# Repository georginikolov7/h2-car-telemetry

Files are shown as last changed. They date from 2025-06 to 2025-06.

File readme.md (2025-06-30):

# 🏎️ Hydrogen Racing Car Telemetry – Battery Monitoring

This project enables **real-time battery telemetry** for a **hydrogen-powered racing car**, built for high school competitions. It reads battery capacity using a Seeed XIAO nRF52 BLE board and transmits it via **Bluetooth Low Energy (BLE)** to a **.NET MAUI mobile app**.

> Please read this document carefully to understand the setup, components, and how to continue development.

---

## 📦 Contents

- 📁 `xiaoble-source/` – Firmware code for the Seeed XIAO board (C++ with PlatformIO)
- 📁 `pcb/` – KiCad files for the electrical design
- 📁 `maui-source/` – code for the mobile app (C# MAUI framework)
- 📄 `README.md` – Project documentation (you are here)

---

## ⚙️ System Overview

- **Board**: Seeed XIAO nRF52 BLE
- **Function**: Reads battery voltage/capacity and transmits data via BLE
- **Receiver**: Mobile app built with .NET MAUI
- **Firmware**: C++ using PlatformIO + Bluefruit library

---

## 🧰 Tools & Dependencies

### Hardware

- Seeed XIAO nRF52 BLE board
- Battery and voltage measuring circuit (see `pcb/`)
- Bluetooth-capable mobile device (Android)

### Parameters to keep in mind
Battery:
- Minimal voltage before cut-off - 6.4V
- Maximal charge voltage - 8.6V
---
!!! Since battery voltage range IS OUTSIDE working range of the seeed XIAO board, a voltage divider circuit is used to reduce the supplied voltage before passing it to analog input on the board !!!
---
### Software

- [PlatformIO](https://platformio.org/) (for microcontroller firmware)
- [KiCad](https://kicad.org/) (for circuit schematics)
- [.NET MAUI](https://learn.microsoft.com/en-us/dotnet/maui/) (for the mobile app)

---

## 📚 Used Libraries

### 🧠 Microcontroller (Seeed XIAO nRF52 BLE)

- **[Adafruit Bluefruit nRF52 Library](https://github.com/adafruit/Adafruit_nRF52_Arduino)**  
  Provides BLE support for nRF52 chips. Used to advertise services, send battery data, and manage BLE characteristics.

> No additional installation required

### 📱 Mobile App (MAUI)

- [Plugin.BLE](https://github.com/xabre/xamarin-bluetooth-le) by xabre  
  Cross-platform BLE plugin for Xamarin/.NET MAUI. Used to scan, connect, and read BLE data from the XIAO board.

Add via NuGet:

```bash
dotnet add package Plugin.BLE
```
---
## 🛠️ Getting Started

### Hardware 
- Please familiarize yourselves with the schematic design and used components (the power )

### 🚀 Firmware Setup (Microcontroller)

1. Install [Visual Studio Code](https://code.visualstudio.com/) with the [PlatformIO extension](https://platformio.org/install).
2. Open the project folder in VSCode.
3. Connect the Seeed XIAO nRF52 BLE board via USB.
4. Upload the firmware:

```bash
pio run --target upload
```
## 💡 Future Improvement Ideas

### 🧪 Add sensors for:

- Measure consumed current(use a ready-made board with low quiescent current. Ideally it should not rely on shunt resistors as such ones consume more power)  

- Hydrogen flow measurement

- Motor/controller temperature

- Wheel speed or RPM

### 📱 Improve the mobile app:

- Real-time graphs

- Database

## 🙏 Acknowledgments
Originally developed by Georgi Nikolov as part of the high school hydrogen racing program.
Now handed off to the next generation — good luck and keep innovating!

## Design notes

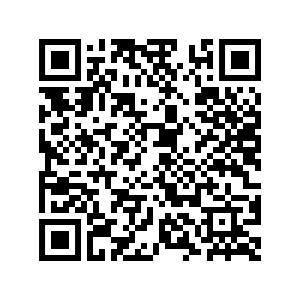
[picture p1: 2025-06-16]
H2CarApp.png

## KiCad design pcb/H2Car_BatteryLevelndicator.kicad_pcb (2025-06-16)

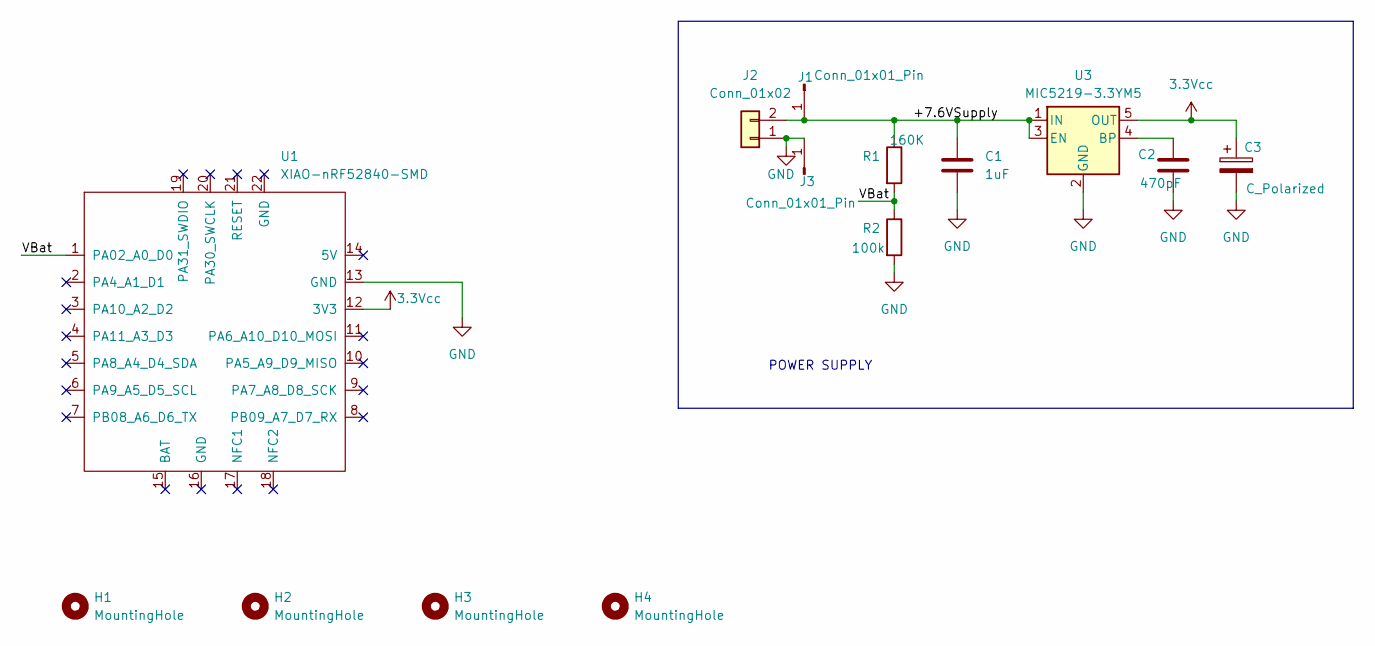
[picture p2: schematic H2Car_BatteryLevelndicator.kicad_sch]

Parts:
C1: 1uF; C_1206_3216Metric
C2: 470pF; C_0201_0603Metric
C3: C_Polarized; CP_EIA-3528-21_Kemet-B
H1, H2, H3, H4: MountingHole; MountingHole_2.2mm_M2_DIN965
J1, J3: Conn_01x01_Pin; SolderWire-0.75sqmm_1x01_D1.25mm_OD3.5mm
J2: Conn_01x02; JST_XH_S2B-XH-A_1x02_P2.50mm_Horizontal
R1: 160K; R_0805_2012Metric
R2: 100k; R_0805_2012Metric
U1: XIAO-nRF52840-SMD
U3: MIC5219-3.3YM5; SOT-23-5

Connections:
3.3Vcc: C3.1, U1.12 (3V3), U3.5 (OUT)
/+7.6VSupply: C1.1, J1.1, J2.2, R1.1, U3.1 (IN), U3.3 (EN)
/VBat: R1.2, R2.1, U1.1 (PA02_A0_D0)
GND: C1.2, C2.2, C3.2, J2.1, J3.1, R2.2, U1.13 (GND), U3.2 (GND)
unnamed: C2.1, U3.4 (BP)

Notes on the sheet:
POWER SUPPLY

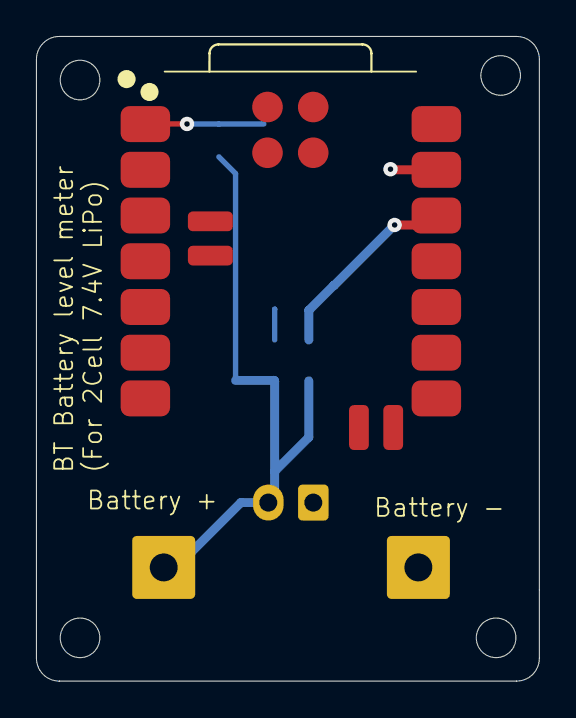
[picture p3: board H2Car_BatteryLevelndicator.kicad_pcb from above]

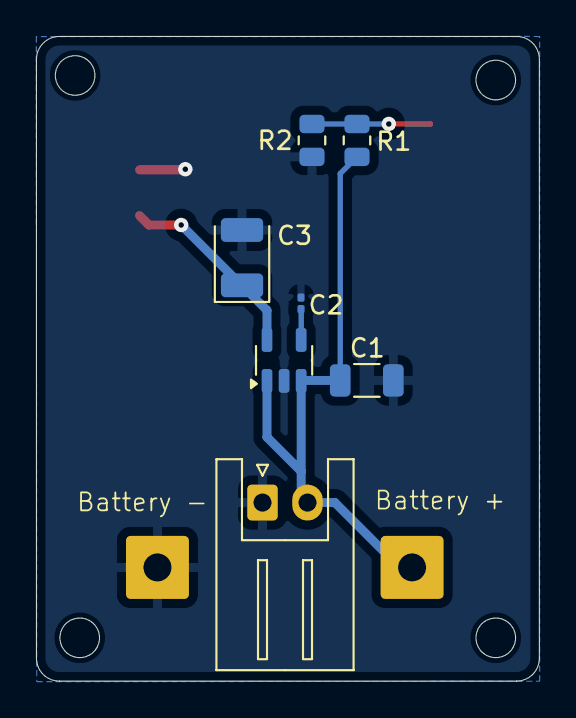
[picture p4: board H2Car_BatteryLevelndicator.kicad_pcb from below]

Board: 2 copper layers, 27.9 x 35.8 mm, 14 parts (7 on the bottom side), 5 nets.

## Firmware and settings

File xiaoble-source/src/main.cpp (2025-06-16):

#include <Arduino.h>
#include <bluefruit.h>
#include <nrf_nvic.h>
#include <nrf_sdm.h>

// CONSTANTS:
const int Sleep_Time = 3000;
#define BatteryPin A0
const char* deviceName = "H2Car";

const int Battery_Min_Voltage = 6.4;
const int Battery_Max_Voltage = 8.6;

// VALUES:
int batteryReadVal = 0;
double batteryPercentage = 0;
int roundedPercentage = 0;

// BLE OBJECTS:
BLEService batService(0x180F);
BLECharacteristic batStatus(0x2A19);

// FUNCTION DECLARATIONS:
void connect_callback(uint16_t conn_handle);
void disconnect_callback(uint16_t conn_handle, uint8_t reason);
void startAdvertising();
void setupBle();

void setup()
{
    // Serial.begin(115200);

    pinMode(BatteryPin, INPUT);
    analogReadResolution(12);
    setupBle();
    delay(20);

    Serial.println("Setup complete!");
}

void loop()
{
    // Read battery level input:
    batteryReadVal = analogRead(BatteryPin);
    Serial.printf("Read val: %i \n\r", batteryReadVal);
    
    // Equation for battery percentage: bat% = 0.21*(analogRead - 477.27*Vbatmin)/(Vbatmax-Vbatmin)
    batteryPercentage = (0.21 * (batteryReadVal - 477.27 * Battery_Min_Voltage) / (Battery_Max_Voltage - Battery_Min_Voltage));

    // Round percentage:
    roundedPercentage = 5 * round(batteryPercentage / 5.0);
    Serial.println(roundedPercentage);

    // Validate boundaries:
    if (roundedPercentage < 0) {
        roundedPercentage = 0;
    } else if (roundedPercentage > 100) {
        roundedPercentage = 100;
    }

    // Notify connected client with the analog value
    batStatus.notify8(roundedPercentage);

    // Serial.printf("Analog read: %i\n\r", batteryReadVal);
    // Serial.printf("Percentage: %f\n\r", batteryPercentage);

    delay(Sleep_Time); // Wait before sending the next value
}

void connect_callback(uint16_t conn_handle)
{
    Serial.println("Connected!");
}

void disconnect_callback(uint16_t conn_handle, uint8_t reason)
{
    Serial.println("Disconnected!");
}
void startAdvertising()
{
    // Bluefruit.Advertising.addService(batService);
    Bluefruit.Advertising.addFlags(BLE_GAP_ADV_FLAGS_LE_ONLY_GENERAL_DISC_MODE);
    Bluefruit.Advertising.addTxPower();
    Bluefruit.Advertising.addName();

    Bluefruit.Advertising.start();
}

void setupBle()
{
    // Initialize Bluefruit
    Serial.println("Starting BLE");
    Bluefruit.begin();
    Bluefruit.setTxPower(4); // Max transmit power
    Bluefruit.setName(deviceName); // BLE device name
    Bluefruit.Periph.setConnectCallback(connect_callback);
    Bluefruit.Periph.setDisconnectCallback(disconnect_callback);

    Serial.println("Attaching service");
    // Add custom BLE service
    err_t error = batService.begin();
    Serial.println(error);
    Serial.println("Attaching characteristic");

    // Add characteristic to the custom service
    batStatus.setProperties(CHR_PROPS_NOTIFY | CHR_PROPS_READ);
    batStatus.setPermission(SECMODE_OPEN, SECMODE_NO_ACCESS);
    batStatus.setFixedLen(2); // 2 bytes for a 16-bit analog value
    error = batStatus.begin();
    Serial.println(error);
    // Start advertising
    startAdvertising();
}

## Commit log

2025-06-16 Init commit
    [H2Car_BatteryLevelndicator-B_Cu.gbr, H2Car_BatteryLevelndicator-B_Mask.gbr, H2Car_BatteryLevelndicator-B_Paste.gbr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]
2025-06-16 Added readme.md and renamed folders
    [H2Car_BatteryLevelndicator-B_Cu.gbr, H2Car_BatteryLevelndicator-B_Mask.gbr, H2Car_BatteryLevelndicator-B_Paste.gbr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]
2025-06-30 Include battery parameters in readme. Make schematic design more readable.
    [H2Car_BatteryLevelndicator.kicad_sch]
